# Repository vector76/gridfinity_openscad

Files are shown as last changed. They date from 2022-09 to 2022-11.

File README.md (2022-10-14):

# Gridfinity OpenSCAD Model
This is a recreation of Zack Freedman's gridfinity system in OpenSCAD, 
intended for both experienced OpenSCAD users to customize with added features, 
and also less-experienced OpenSCAD users to customize via options offered in the customizer.

The fit-related dimensions are intended to match Zack's original design exactly.

Options for bins:
* Screw holes are optional, or alternative lengths can be specified
* Magnet pockets are optional, or alternative diameters can be specified
* User-selectable wall thickness and floor thickness
* Generate a filled-in block as a starting point for generating other models (similar in spirit to [this](https://www.printables.com/model/210548-filled-in-gridfinity-boxes-for-customization))
* Any number of subdivisions along X axis (only X subdivisions are implemented)
* Irregular subdivisions along X axis (only X subdivisions are implemented)
* Finger-slide for removing small parts, available as an option
* Label feature available as an option
* Label feature can cover entire X length or only part
* Label feature can be left-justified, right-justified, or centered
* Magnet/screw hole can have printable overhangs as an option (if screw holes and magnet pockets are both used) (similar in spirit to [this](https://www.printables.com/model/269834-gridfinity-template-modified-for-mid-air-holes))
* Option for material-efficient floor that is not flat but saves material/time (similar in spirit to [this](https://www.printables.com/model/265271-gridfinity-lite-economical-plain-storage-bins))
* Fractional-width bins (0.5 units) supported (similar in spirit to [this](https://www.printables.com/model/241907-gridfinity-half-boxes-up-to-3-grids-long-and-6u-hi))

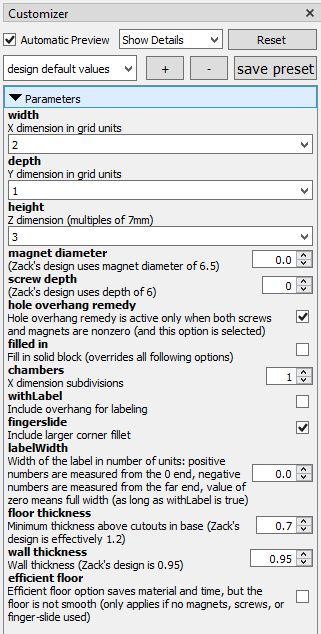
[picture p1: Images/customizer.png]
[]()

Some other models are also included and are also parametric.  Not all of these will be interesting to most people.  Some of them are cosntructions for my own personal use.
* Gridfinity base options
  * Base (just frame)
  * Weighted base includes space for weights and/or screws or magnets
  * Lid/base combination can stack on top of bins and provides base for stacking on top (e.g. for stacking a 1x1 on top of a 3x3)
* Glue stick holder
* Socket holder
* Gridfinity base for Flsun Q5
* Silverware drawer

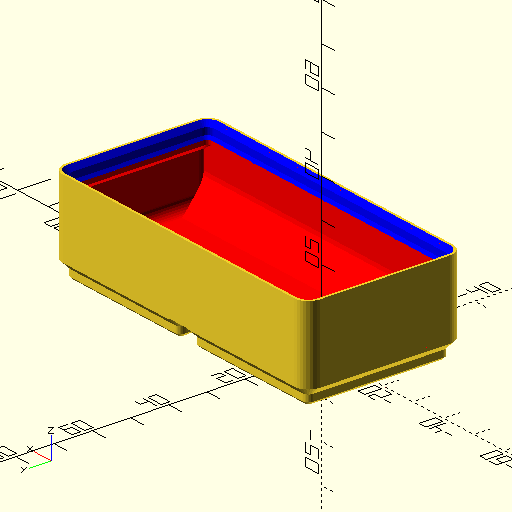
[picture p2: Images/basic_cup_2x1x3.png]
[]()
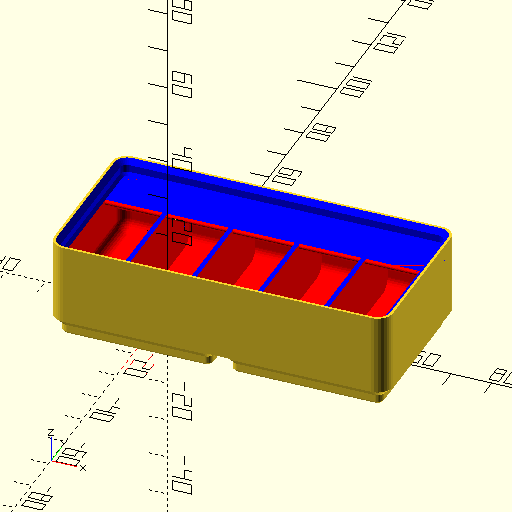
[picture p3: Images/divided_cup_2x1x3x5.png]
[]()
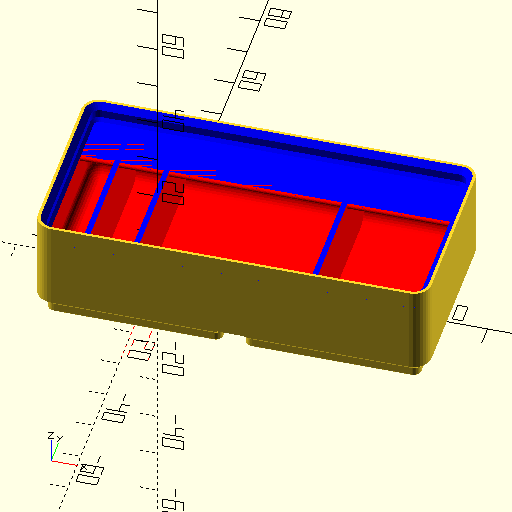
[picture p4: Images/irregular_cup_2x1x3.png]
[]()
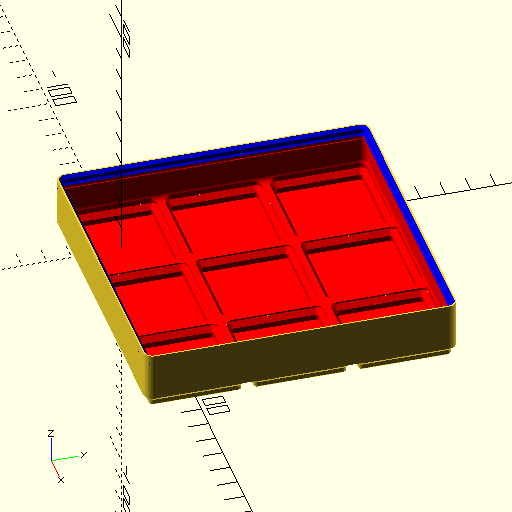
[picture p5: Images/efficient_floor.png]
[]()
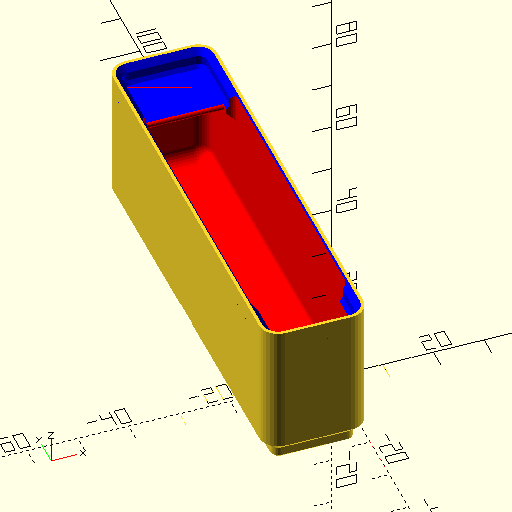
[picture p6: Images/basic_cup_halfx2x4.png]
[]()
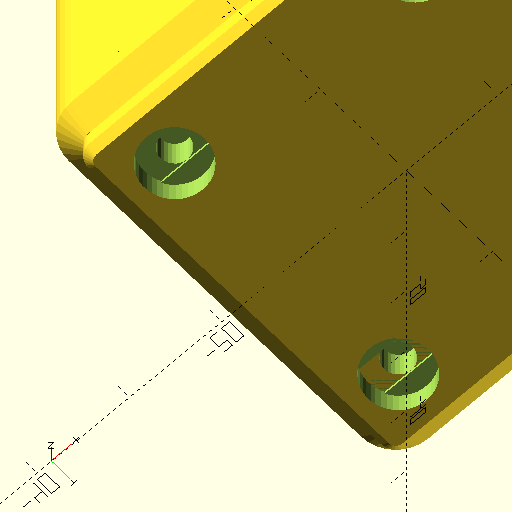
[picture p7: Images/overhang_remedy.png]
[]()
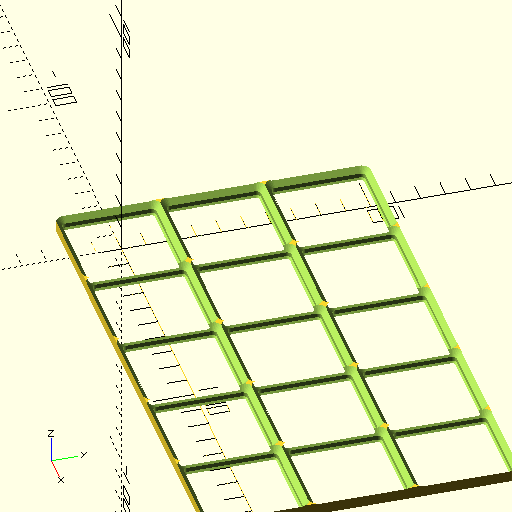
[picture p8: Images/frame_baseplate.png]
[]()
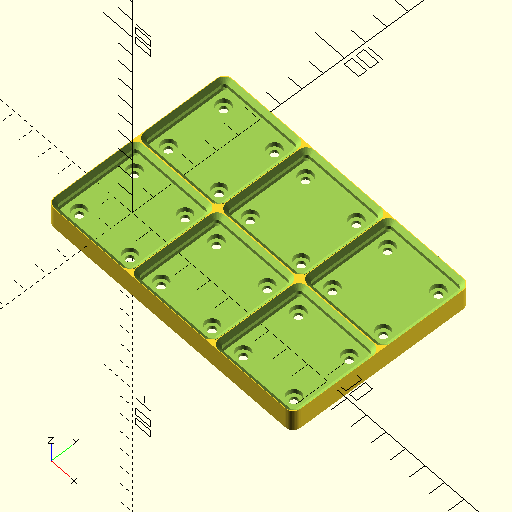
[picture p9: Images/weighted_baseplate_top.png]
[]()
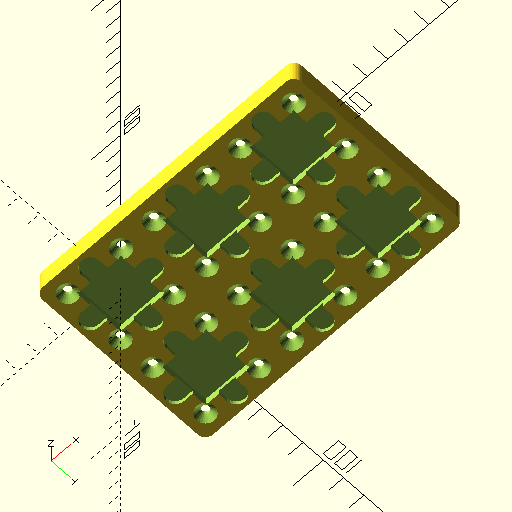
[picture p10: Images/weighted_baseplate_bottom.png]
[]()
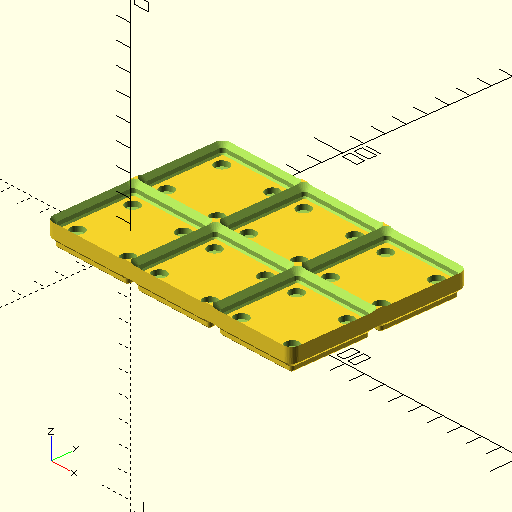
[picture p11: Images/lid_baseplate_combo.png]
[]()

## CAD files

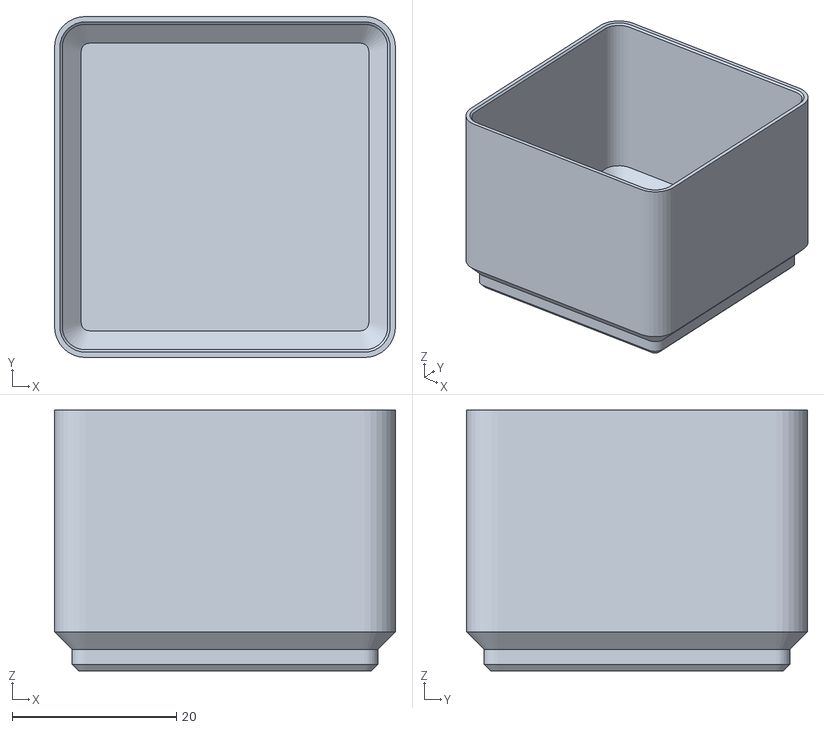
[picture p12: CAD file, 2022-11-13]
Renders/basic_cup_1x1x3_nolip.stl
41.5 x 41.5 x 31.8

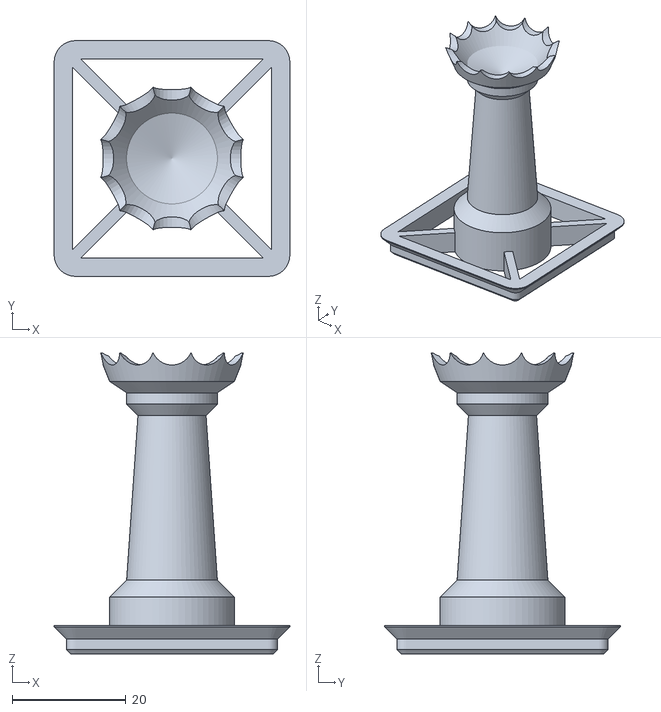
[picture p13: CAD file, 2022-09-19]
Renders/chess/queen.stl
41.5 x 41.5 x 53.0

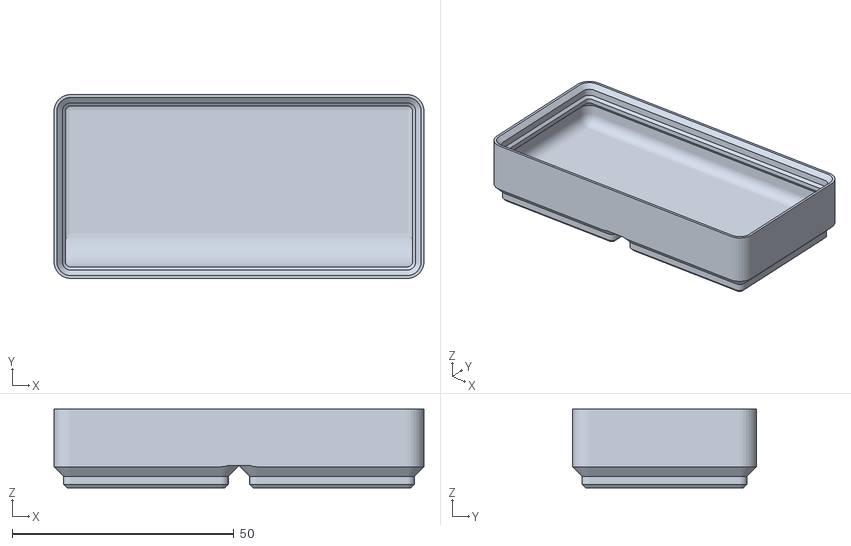
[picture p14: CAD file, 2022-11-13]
Renders/basic_cup_2x1x2.stl
83.5 x 41.5 x 17.8

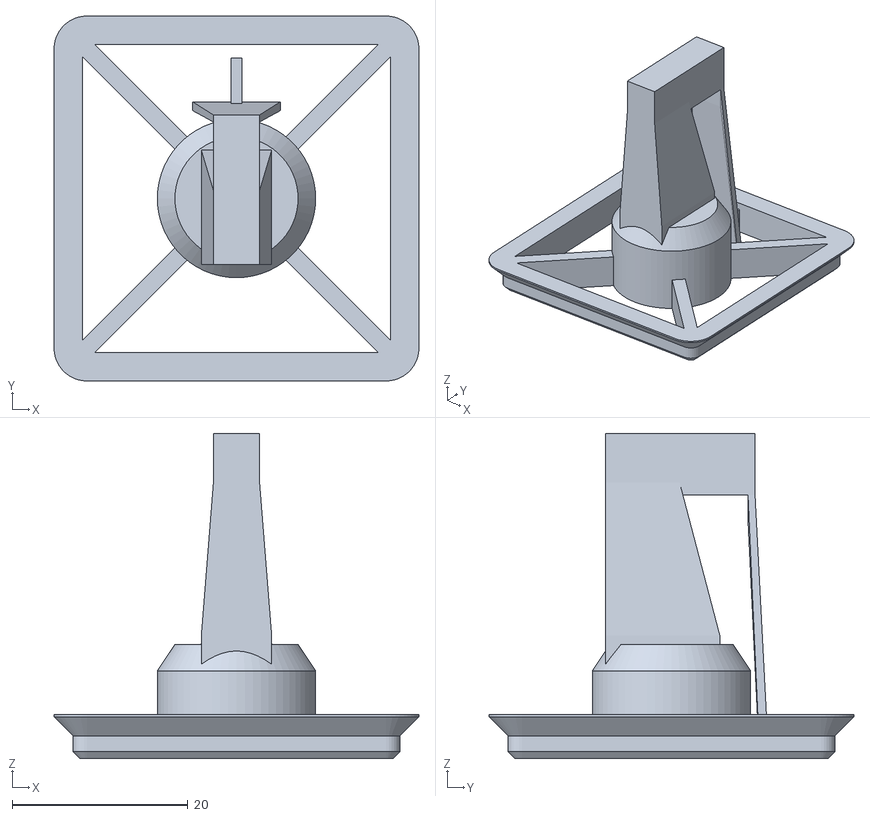
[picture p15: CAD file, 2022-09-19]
Renders/chess/knight.stl
41.5 x 41.5 x 37.0

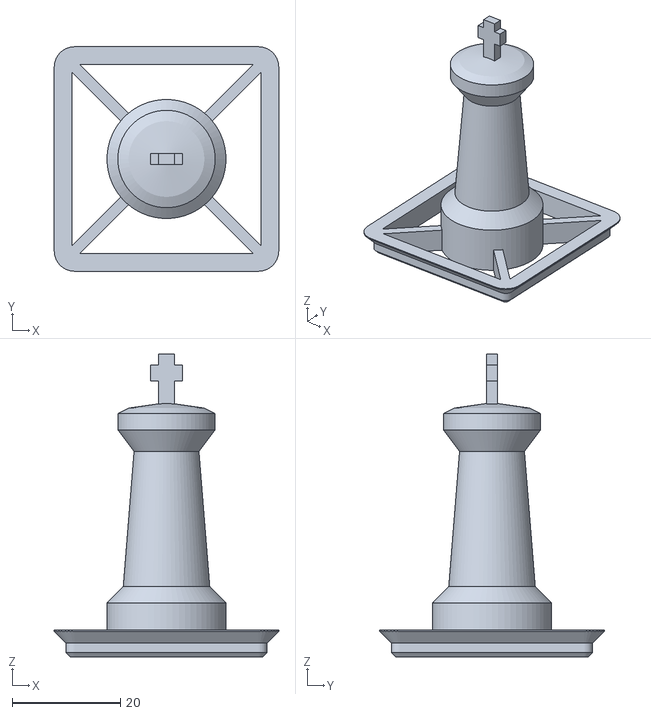
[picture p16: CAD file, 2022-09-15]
Renders/chess/king.stl
41.5 x 41.5 x 56.0

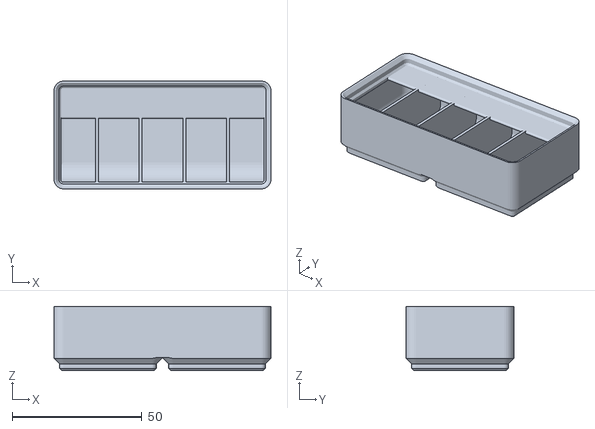
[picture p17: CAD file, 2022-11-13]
Renders/divided_cup_2x1x3x5.stl
83.5 x 41.5 x 24.8

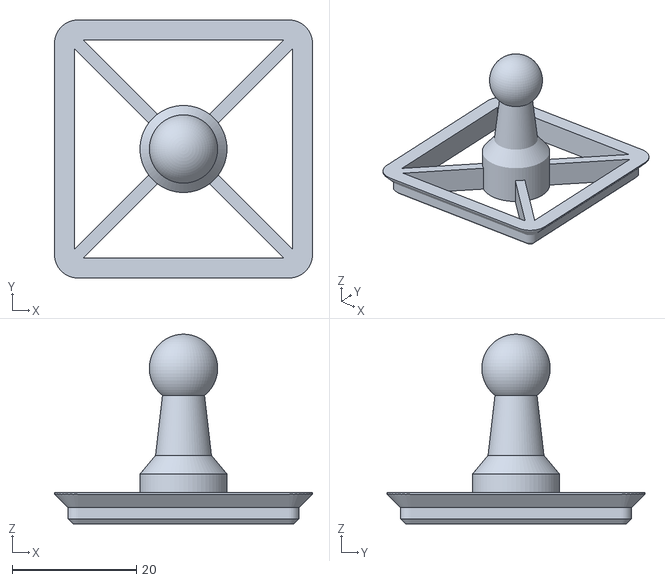
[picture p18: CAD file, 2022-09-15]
Renders/chess/pawn.stl
41.5 x 41.5 x 30.5

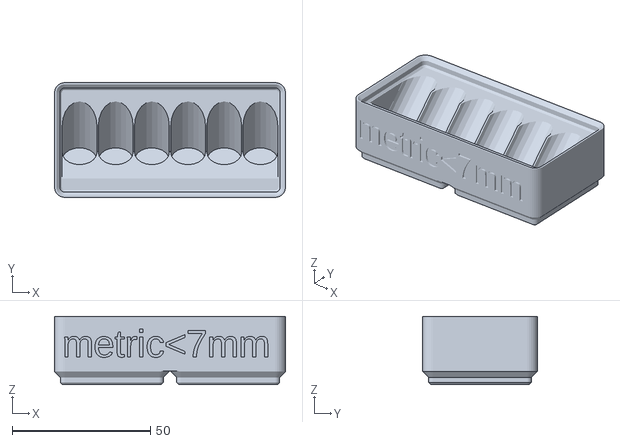
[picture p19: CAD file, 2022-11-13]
Renders/socket_holder_metric_small.stl
83.5 x 41.5 x 24.8

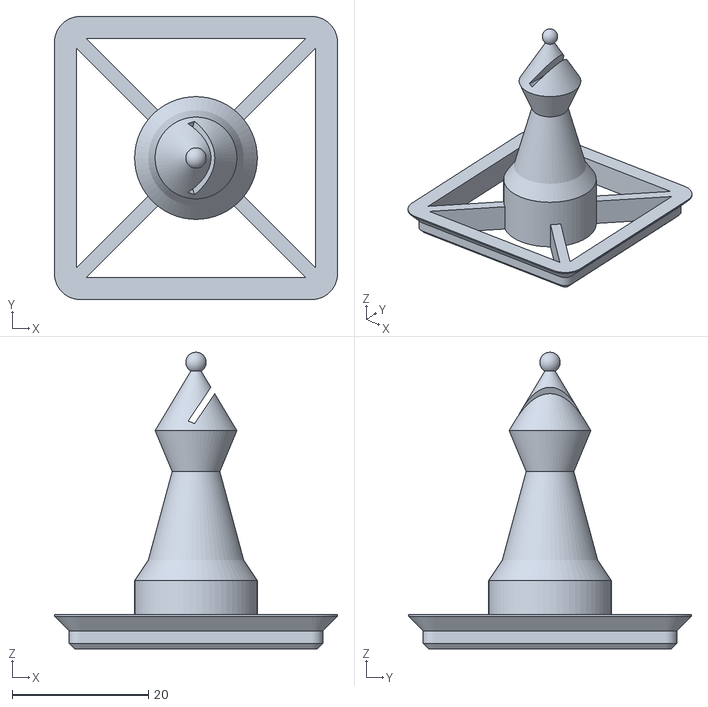
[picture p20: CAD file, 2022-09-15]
Renders/chess/bishop.stl
41.5 x 41.5 x 43.5

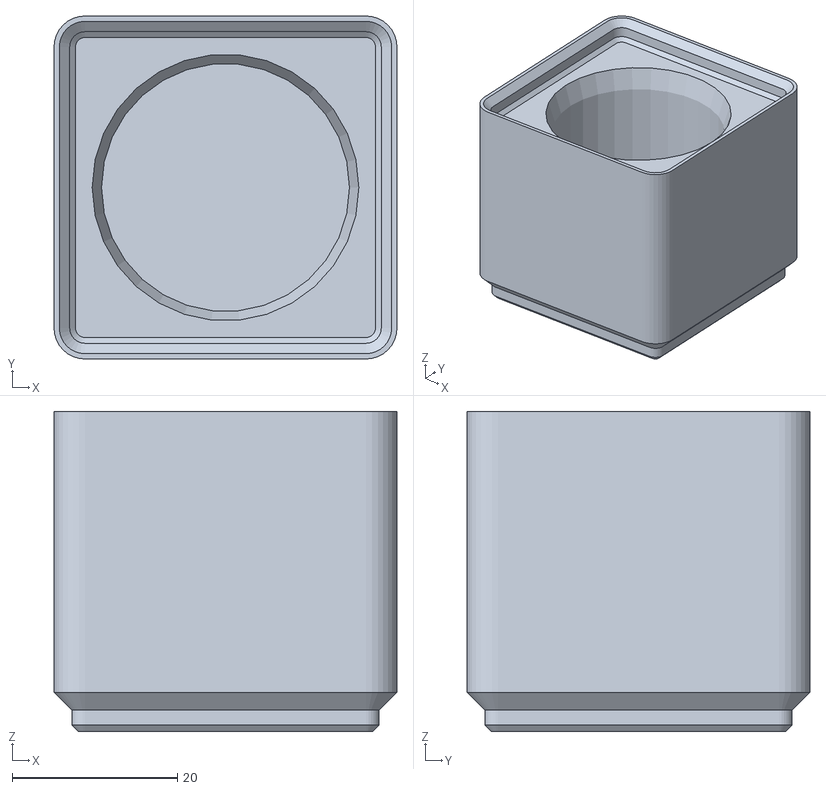
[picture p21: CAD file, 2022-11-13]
Renders/glue_stick_cup.stl
41.5 x 41.5 x 38.8

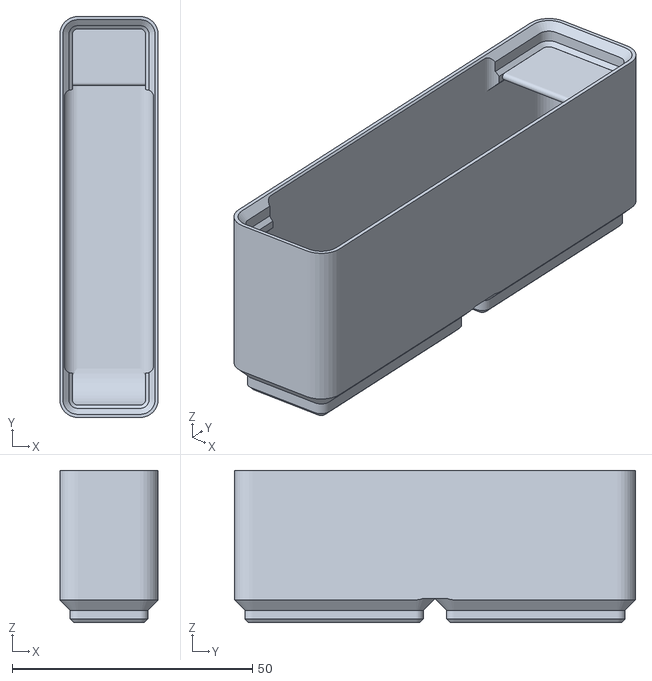
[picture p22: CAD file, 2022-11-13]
Renders/basic_cup_halfx2x4.stl
20.5 x 83.5 x 31.8

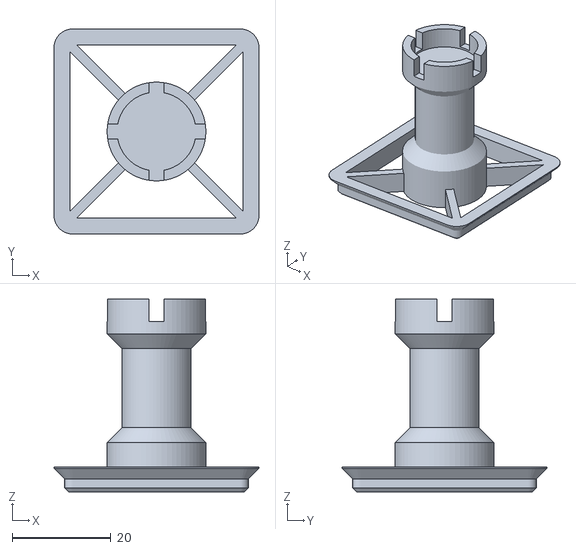
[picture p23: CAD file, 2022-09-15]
Renders/chess/rook.stl
41.5 x 41.5 x 39.0

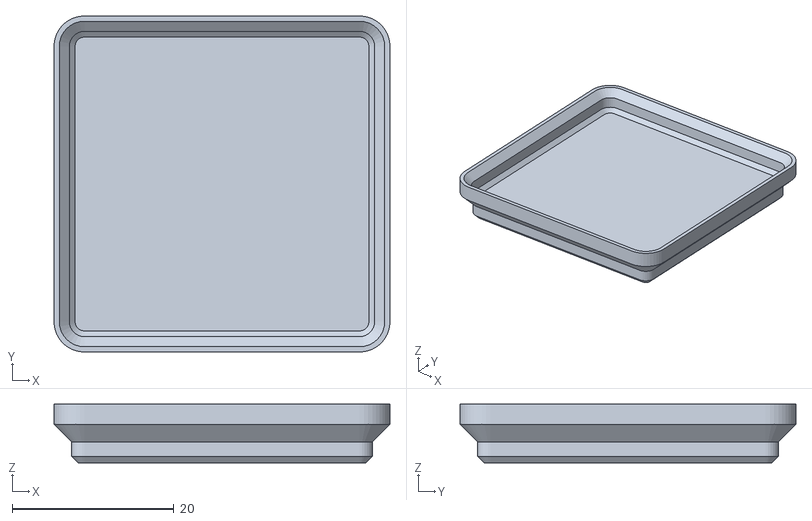
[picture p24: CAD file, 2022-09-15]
Renders/chess/tile.stl
41.5 x 41.5 x 7.25

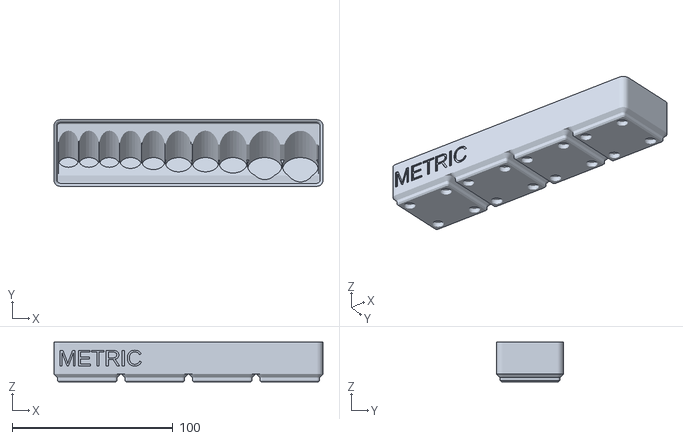
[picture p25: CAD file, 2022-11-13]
Renders/socket_holder_metric.stl
167.5 x 41.5 x 24.8

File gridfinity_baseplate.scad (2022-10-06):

// include instead of use, so we get the pitch
include <gridfinity_modules.scad>

xsize = 5;
ysize = 3;
weighted = false;
lid = false;

if (lid) {
  base_lid(xsize, ysize);
}
else if (weighted) {
  weighted_baseplate(xsize, ysize);
}
else {
  frame_plain(xsize, ysize);
}


module base_lid(num_x, num_y) {
  magnet_od = 6.5;
  magnet_position = min(gridfinity_pitch/2-8, gridfinity_pitch/2-4-magnet_od/2);
  magnet_thickness = 2.4;
  eps = 0.1;
  
  translate([0, 0, 7]) frame_plain(xsize, ysize, trim=0.25);
  difference() {
    grid_block(xsize, ysize, 1, magnet_diameter=0, screw_depth=0);
    gridcopy(num_x, num_y) {
      cornercopy(magnet_position) {
        translate([0, 0, 7-magnet_thickness])
        cylinder(d=magnet_od, h=magnet_thickness+eps, $fn=48);
      }
    }
  }
}


module weighted_baseplate(num_x, num_y) {
  magnet_od = 6.5;
  magnet_position = min(gridfinity_pitch/2-8, gridfinity_pitch/2-4-magnet_od/2);
  magnet_thickness = 2.4;
  eps = 0.1;
  
  difference() {
    frame_plain(num_x, num_y, 6.4);
    
    gridcopy(num_x, num_y) {
      cornercopy(magnet_position) {
        translate([0, 0, -magnet_thickness])
        cylinder(d=magnet_od, h=magnet_thickness+eps, $fn=48);
        
        translate([0, 0, -6.4]) cylinder(d=3.5, h=6.4, $fn=24);
        
        // counter-sunk holes in the bottom
        translate([0, 0, -6.41]) cylinder(d1=8.5, d2=3.5, h=2.5, $fn=24);
      }
      
      translate([-10.7, -10.7, -6.41]) cube([21.4, 21.4, 4.01]);
      
      for (a2=[0,90]) rotate([0, 0, a2])
      hull() for (a=[0, 180]) rotate([0, 0, a])
      translate([-14.9519, 0, -6.41]) cylinder(d=8.5, h=2.01, $fn=24);
    }
  }
}


module frame_plain(num_x, num_y, extra_down=0, trim=0) {
  ht = extra_down > 0 ? 4.4 : 5;
  corner_radius = 3.75;
  corner_position = gridfinity_pitch/2-corner_radius-trim;
  difference() {
    hull() cornercopy(corner_position, num_x, num_y) 
    translate([0, 0, -extra_down]) cylinder(r=corner_radius, h=ht+extra_down, $fn=44);
    translate([0, 0, trim ? 0 : -0.01]) 
    render() gridcopy(num_x, num_y) pad_oversize(margins=1);
  }
}

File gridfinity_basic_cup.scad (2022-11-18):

// include <gridfinity_modules.scad>
use <gridfinity_cup_modules.scad>

// X dimension in grid units
width = 2; // [ 0.5, 1, 2, 3, 4, 5, 6, 7, 8, 9, 10, 11, 12, 13 ]
// Y dimension in grid units
depth = 1; // [ 1, 2, 3, 4, 5, 6, 7, 8, 9, 10, 11, 12, 13 ]
// Z dimension (multiples of 7mm)
height = 3;
// (Zack's design uses magnet diameter of 6.5)
magnet_diameter = 0;  // .1
// (Zack's design uses depth of 6)
screw_depth = 0;
// Hole overhang remedy is active only when both screws and magnets are nonzero (and this option is selected)
hole_overhang_remedy = true;
//Only add attachments (magnets and screw) to box corners (prints faster).
box_corner_attachments_only = false;
// Fill in solid block (overrides all following options)
filled_in = false;
// X dimension subdivisions
chambers = 1;
// Include overhang for labeling (and specify left/right/center justification)
withLabel = "disabled"; // ["disabled", "left", "right", "center", "leftchamber", "rightchamber", "centerchamber"]
// Include larger corner fillet
fingerslide = true;
// Width of the label in number of units, or zero means full width
labelWidth = 0;  // .01
// Minimum thickness above cutouts in base (Zack's design is effectively 1.2)
floor_thickness = 0.7;
// Wall thickness (Zack's design is 0.95)
wall_thickness = 0.95;  // .01
// Efficient floor option saves material and time, but the floor is not smooth (only applies if no magnets, screws, or finger-slide used)
efficient_floor = false;
// When enabled, irregular subdivisions have to be defined in code
irregular_subdivisions = false;
// Enable to subdivide bottom pads to allow half-cell offsets
half_pitch = false;
// Remove some or all of lip
lip_style = "normal";  // [ "normal", "reduced", "none" ]

module end_of_customizer_opts() {}

// Separator positions are defined in terms of grid units from the left end
separator_positions = [ 0.25, 0.5, 1.4 ];

if (filled_in) {
  grid_block(width, depth, height, magnet_diameter=magnet_diameter, 
    screw_depth=screw_depth, hole_overhang_remedy=hole_overhang_remedy,
    half_pitch=half_pitch, box_corner_attachments_only=box_corner_attachments_only);
}
else if (irregular_subdivisions) {
  irregular_cup(
    num_x=width,
    num_y=depth,
    num_z=height,
    withLabel=withLabel,
    labelWidth=labelWidth,
    fingerslide=fingerslide,
    magnet_diameter=magnet_diameter,
    screw_depth=screw_depth,
    floor_thickness=floor_thickness,
    wall_thickness=wall_thickness,
    hole_overhang_remedy=hole_overhang_remedy,
    separator_positions=separator_positions,
    half_pitch=half_pitch,
    lip_style=lip_style,
    box_corner_attachments_only=box_corner_attachments_only
  );
}
else {
  basic_cup(
    num_x=width,
    num_y=depth,
    num_z=height,
    chambers=chambers,
    withLabel=withLabel,
    labelWidth=labelWidth,
    fingerslide=fingerslide,
    magnet_diameter=magnet_diameter,
    screw_depth=screw_depth,
    floor_thickness=floor_thickness,
    wall_thickness=wall_thickness,
    hole_overhang_remedy=hole_overhang_remedy,
    efficient_floor=efficient_floor,
    half_pitch=half_pitch,
    lip_style=lip_style,
    box_corner_attachments_only=box_corner_attachments_only
  );
}

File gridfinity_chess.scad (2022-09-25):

include <gridfinity_modules.scad>

// Select model
part = "tile";  // [ board, tile, pawn, knight, bishop, rook, queen, king ]

if (part == "tile") {
  tile();
}
else if (part == "pawn") {
  pawn();
}
else if (part == "knight") {
  knight();
}
else if (part == "bishop") {
  bishop();
}
else if (part == "rook") {
  rook();
}
else if (part == "queen") {
  queen();
}
else if (part == "king") {
  king();
}
else if (part == "board") {
  board();
  color("#DDDDDD") piece_set();
  color("#505050") piece_set(false);
}


module piece_set(white=true) {
  pawnrow = white ? 1 : 6;
  restrow = white ? 0 : 7;
  
  for (i=[0:7]) {
    translate([i*42, 42*pawnrow, 0]) pawn();
  }
  for (i=[0,1]) {
    translate([0 + 7*i*42, restrow*42, 0]) rook();
    translate([(1 + 5*i)*42, restrow*42, 0]) 
      rotate([0, 0, white ? 0 : 180]) knight();
    translate([(2 + 3*i)*42, restrow*42, 0]) bishop();
  }
  translate([3*42, restrow*42, 0]) queen();
  translate([4*42, restrow*42, 0]) king();
}


module king() {
  base();
  
  rotate_extrude($fn=60)
  polygon([[0, 47], [0, 0], [11, 0], [11, 10], [8, 13], [6, 38],
    [9, 42], [9, 45], [7, 46]]);
  
  translate([-1.5, -1, 47-1]) cube([3, 2, 10]);
  translate([-3, -1, 51]) cube([6, 2, 3]);
}


module queen() {
  base();
  
  difference() {  
    rotate_extrude($fn=60)
    polygon([[0, 45], [0, 0], [11, 0], [11, 10], [8, 13], [6, 42], 
      [8, 44], [8, 46], [11, 48], [13, 53], [12, 53], [8, 48]]);
    
    *%for (a=[0, 60, 120]) rotate([0, 0, a])
    translate([-15, -1.5, 48.5]) cube([30, 3, 10]);
    
    for (a=[0, 30, 60, 90, 120, 150]) rotate([0, 0, a])
    translate([0, 0, 48.5+6])
    rotate([0, 90, 0]) cylinder(d=7.25, h=30, $fn=30, center=true);
  }
}


module knight() {
  base();

  rotate_extrude($fn=60)
  polygon([[0, 13], [0, 0], [9, 0], [9, 10], [7, 13]]);
  
  hull() {
    translate([-4, -7.5, 0]) cube([8, 13, 14]);
    translate([-2.5, -7.5, 30]) cube([5, 8, 3]);
  }
  translate([-2.5-.125, -7.5, 30]) cube([5+.25, 17, 7]);
  
  // support for bridging knight nose (remove afterward)
  hull() {
    translate([-2.625, 9.5-0.8, 27]) cube([5.25, 0.8, 3]);  
    translate([-5, 10, 0]) cube([10, 1, 1]);
  }
  translate([-0.6, 10, 0]) cube([1.2, 6, 5]);
}


module bishop() {
  base();
  
  tz(42) sphere(d=3, $fn=60);
  
  difference() {
    rotate_extrude($fn=60)
    polygon([[0, 42], [0, 0], [9, 0], [9, 10], [7, 13], [3.5, 26], [6, 32]]);
    
    translate([4.5, 0, 40])
    rotate([0, -56, 0])
    cylinder(d=20, h=1, $fn=60);
  }
}


module rook() {
  base();
  
  difference() {
    rotate_extrude($fn=60)
    polygon([[0, 34], [0, 0], [10, 0], [10, 10], [7, 13], [7, 29], 
      [10, 32], [10, 39], [8, 39], [8, 34]]);
    
    for (a=[0, 90]) rotate([0, 0, a]) 
      translate([-15, -1.5, 34.5]) cube([30, 3, 10]);
  }
}


module pawn() {
  base();
  
  tz(25) sphere(d=11, $fn=60);
  
  rotate_extrude($fn=60)
  polygon([[0, 25], [0, 0], [7, 0], [7, 8], [4.5, 11], [3, 24]]);
}


module base() {
  difference() {
    grid_block(1, 1, 0.72, magnet_diameter=0, screw_depth=0);
    difference() {
      cube([35, 35, 30], center=true);
      for (a=[45, 135]) rotate([0, 0, a]) cube([60, 2, 30], center=true);
    }
    
    translate([-21, -21, 5]) cube([42, 42, 42]);
  }
}


module board() {  // 64 tiles in alternating colors
  tz(-3.55) for (ti=[0:7]) for (tj=[0:7]) translate([42*ti, 42*tj, 0]) 
    color((ti+tj)%2 == 0 ? "darkblue" : "lightblue")
    render() tile();
}


module tile() {
  grid_block(1, 1, 0.5, magnet_diameter=0, screw_depth=0);
}


module tz(z) {
  translate([0, 0, z]) children();
}

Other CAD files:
Renders/divided_cup_2x1x2x5.stl
Renders/socket_holder_imperial.stl
Renders/socket_holder_metric_stacking.stl
Renders/filled_block_2x1x3x5.stl
gridfinity_cup_modules.scad
Renders/base_lid.stl
Renders/baseplate.stl
Renders/flsun_q5.stl
Renders/socket_holder_imperial_big.stl
Renders/socket_holder_imperial_small.stl
Renders/weighted_baseplate.stl
gridfinity_flsun_q5.scad
gridfinity_glue_stick.scad
gridfinity_modules.scad
gridfinity_silverware.scad
gridfinity_socket_holder.scad
modules/gridfinity_cup_modules.scad
modules/gridfinity_modules.scad

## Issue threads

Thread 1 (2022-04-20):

Basic cup should be centered

RussNelson, 2022-04-20:
If you create a basic cup with any values other than 1,1 only the first grid unit is centered. The whole module should be centered.

RussNelson, 2022-04-20:
I suggest this because the largest glue stick you can hold without overlapping the edges is 34mm. Bigger than that, and it needs to use a 2x2 storage unit to hold the stick.

vector76, 2022-04-21:
I've updated grid block to have an option to center the assembly in X/Y (but not Z), somewhat analogous to the option in the native OpenSCAD cube().  7a81cb26ac3db598b1b274acb1f8680bb33545fa

Closed 2022-04-21.

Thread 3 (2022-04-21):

why import?

RussNelson, 2022-04-21:
Why are Zack's baseplates being imported into gridfinity_baseplate.scad? Is that just for comparison's sake?
Also, the simple baseplate's holes are not fully cut out. I had to make this change. Is this correct?
-    render() gridcopy(num_x, num_y) pad_oversize(margins=1);
+    translate([0,0,-0.01]) render() gridcopy(num_x, num_y) pad_oversize(margins=1);

vector76, 2022-04-21:
oops!  I meant to remove those imports.  I use those during construction to confirm the dimensions match exactly.

The plain frame has a negative space that coincides with the bottom of the positive space, which doesn't render properly in preview mode (appears not fully cut out) but when rendered it is fully cut out.  Shifting downward by 0.01 will fix the preview at the expense of a very small deviation from Zack's models.  Overall, I think it is close enough and the preview appearance does matter, so I'm willing to include your update for that.

vector76, 2022-04-21:
addressed by 1be92633c44ab8c1248270a54d34d8ec4def1df2

Closed 2022-04-21.

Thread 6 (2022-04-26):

Need to increase bottom thickness; which approach to differences between this and the original?

universalist, 2022-04-26:
Hi there, and thanks a lot for this project!
I've tried it out (with satisfaction and success), but I noticed that there are some differences to the original parts.
Especially the bottom is much thinner, which is a problem because with large layer heights the bottom layer of the compartment becomes just one single layer, resulting in a bad print.
I'd like to propose a fix and create a pull request for that (it would be my very first pull request, but I have experience in OpenSCAD).
I assume that the current bottom thickness was (like the bottom hole height) reduced to maximize the compartment space, so I'd honor that, and would add two options:

1. to set a user-defined minimum thickness above the holes and the bottom cutouts
2. to not maxmize compartment size, but replicate the dimensions of Zacks design

What do you think, does this make sense, would you accept this as a solution? Please let me know what you think.

Regards, Chris

vector76, 2022-04-27:
Yes, I think this makes sense.  Since I was not intending to use the M3 screw holes or magnet holes, I thought it was a waste of space and also a waste of filament to keep the floor height.

By removing (or shortening) the m3 screw holes, the floor can be lower, which I adopted as the default, although I see your point about having an option to more closely mimic Zack's design or choose an alternative floor thickness.

Here is a separate idea that might relate: currently there is an option for holes or no holes, where holes implies the counter-bore holes that fit either M3 screws or magnets.  Since the OpenSCAD design is intended to be more customized and has less need to be universal, I had contemplated making screws or magnets (or both or neither) independent options.

I mention the holes because it creates a constraint where a low floor will have the holes poke through, and without the holes the floor can be lower, and is instead constrained by the grooves between the pads.

What I think would make sense is an option for:
* Magnets: diameter or zero for no magnet holes
* M3 holes: depth or zero for no M3 holes
* Minimum floor thickness

If M3 holes are desired, the minimum floor thickness will create a higher floor, or if M3 holes are not desired or if they are shorter, then the floor will be lower.  The default values for these three options can replicate Zack's design, and the options can be tweaked while maintaining constraints so that the holes won't poke through the floor.

I will give this a think and probably implement it this way.

RussNelson, 2022-04-27:
That is a good idea. You could put the holes / no_holes variable into the top of the file and let the customizer do its thing.

vector76, 2022-08-13:
I believe this last commit implements these features.  The defaults are zero (no hole for screw or magnet) but the values for Zack's design are documented in the customizer (6.0 for screw length and 6.5 for magnet diameter) and the floor thickness causes the floor to be the specified distance above whichever is the tallest.

Open to feedback if I have broken something, but I think this is now complete.

Closed 2022-08-13.

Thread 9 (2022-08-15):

Setting Height above 7 x 7MM

crazyn0va, 2022-08-15:
I was trying to modify the code to allow for a multiple like 11, it shows up fine in the graphic but when I go to export the file I get a different, smaller height. Here is what I have modified:

`// Z dimension (multiples of 7mm)
height = 11;// [2, 3, 4, 5, 6, 7, 8, 9, 10, 11]`

Thanks for helping a SCAD noob.

crazyn0va, 2022-08-15:
Looks like user error, Thanks for the great work!

Closed 2022-08-15.

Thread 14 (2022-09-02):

Not an issue but a question

hvddrift, 2022-09-02:
Re your socket modules. Mine only has one parameter. Should there be more? If not how does it work?

For example if I have a socket set that is

26mm, 25mm, 23mm, 22mm, 17mm etc in diameter can I create a print to suit?

vector76, 2022-09-02:
I had use a single parameter ("part") to generate a small number of variants from a single file, and to generate a custom one you would need to edit the code.

I think you could create what you want by defining part to be 100 or something and then add something like this:
`socket_holder(3, [26,25,23,17], "Custom");`

The first number (3 in this case) is the number of gridfinity units, and the list [26,25,23,17] specifies the number of sockets and their sizes.  The string "Custom" is added as a label and can be whatever you want.

So that should be how you customize it, however, it does look like there is a collision for sockets larger than 24mm and it won't fit properly.  (You can see the red cylinders poking through the model.)

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

If you lower the height by using `num_z` of about 2.3, it looks like it will clear:

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

Hope that helps!

Closed 2022-09-11.

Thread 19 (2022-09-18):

Idea: Half-size bins

rcarmo, 2022-09-18:
I just saw this:

https://www.reddit.com/r/gridfinity/comments/xgn50x/i_have_expanded_my_half_bins_to_9_sizes/

...and it makes a weird kind of sense for some small, long parts (including electronics components, like headers).

Not a priority, but might be an interesting feature to add.

vector76, 2022-09-18:
Huh, interesting.  So if I understand correctly, these
- Still fits on the normal 42 x 42 base cell size
- Only supports half cell width, not say 1.5 or 2.5 cell width
- Length is a whole multiple of cell size
- Stackable on itself
- Magnets and screws in the base probably don't make sense
- Looks like part of the lip is removed for better access

This is interesting.  I like this idea.  I will think about it.

ostat, 2022-09-18:
I'm not sure I would see value in a half sized bin.
Printing two half sized bins would use more plastic than one normal bin with a divider.

That being said being able to set a size in half steps might be handy. Someone might need a size of 3.5x7.5 to fit a specific item, or fill out a draw.

Stacking would be an issue.

vector76, 2022-09-19:
Ok I've made it flexible so it can accept fractional sizes for x (not for y, seems less important).
Added a drop-down to the customizer interface so 0.5 is easily accessible to customizer users without having to guess.
Other fractional values are allowed too, like 0.7 or 0.33 or 1.5.
This is added in commit 7eb04f7131b548b6ddc819d7f7ccfb5450ba0b41 so I'm closing this issue, but I'm still open to feedback, especially if I broke something.

Closed 2022-09-19.

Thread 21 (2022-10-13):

Feature Request: centered labeling shelves

mrmattmorris, 2022-10-13:
The labeling shelves serve two purposes: 1) holding labels;  and 2) acting as a finger catch to lift bins up when they're surrounded by adjacent bins.  As currently implemented, label shelves are always 'left- or right-justified'.  This makes it a bit awkward to lift wide bins that use short label shelves  -- where the lift is happening away from the center of mass.

It could be useful to offer a option to center the label shelves for users who would prefer 'center justification'.

I've already implemented these changes to gridfinity_cup_modules.scad.  I can make a pull request if the owner is interested.

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

mrmattmorris, 2022-10-13:
Whoops, this is already underway as [PR#20](https://github.com/vector76/gridfinity_openscad/pull/20).  Consider this a vote in support.

vector76, 2022-10-13:
Thank you. This has been implemented by #20 but I haven't had a chance to review and merge it. I am guessing will probably be accepting that PR but if you have some commentary, since you have been considering the same issue, I would be interested to hear it.

vector76, 2022-10-13:
Thanks, I will close this issue as essentially duplicate.

Closed 2022-10-13.

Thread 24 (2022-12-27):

Unable to use z-height lower than 2

MrUzagi, 2022-12-27:
This is using the files downloaded from GitHub Dec 13th where the latest modifications dates are Dec 1st (on my computer at GMT +1.)

Setting the height of less than two (actually less than 1.26 after some investigation) the base of the cup is missing the middle bits.

A 1x1 cup with z at 2:
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

A 1x1 cup with z at 1:
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

Editing the height in the script we can check smaller steps.
1.20
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

1.25
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

At 1.26 it looks closed
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

MrUzagi, 2022-12-27:
I've only recently started to familiarize myself with OpenSCAD so I haven't been able to track down the reason for this as of yet.

vector76, 2022-12-27:
Indeed, some of the cutaways for cutting downward from the lip and upward from the bottom were interfering with each other.

I just pushed an update and these are now reduced, and also now it automatically forces 'reduced' or 'none' lip style for very low Z.

Some of the internal fillets are not great, and the finger slide is still broken for low Z, but it should fix the issues you were having.

MrUzagi, 2022-12-31:
Looking good now. Thanks, and happy new year. 🎆

Closed 2022-12-31.

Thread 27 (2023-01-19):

"filled in" should optionally not ignore "lip style"

avxmw, 2023-01-19:
Trying to make a box with a flat top to then cut the shapes for my screwdrivers I noticed I can not fill the box completely, but the lip always remains. I'm trying to make a uniform height without boundaries and for this the lip is in the way.

As such I'd like to request an option to actually fill in everything as cutting of the lip obviously reduces total height.

ostat, 2024-08-06:
I added this suggestion to Gridfinity Extended (which is built on this library). When using filled in, you can chose the lip style.
https://github.com/ostat/gridfinity_extended_openscad

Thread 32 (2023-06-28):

Request - baseplates with half-pitch lid.

Rivenwolf2, 2023-06-28:
Currently, baseplates are only available in standard pitch. This also applies when "lid" option is checked. When bins are set half-pitch, stacking a larger lid to cover adjacent standard-pitch bins causes interference issues.

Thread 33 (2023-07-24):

How to edit total height of a box?

iweputo, 2023-07-24:
Im using customized bin heights and not following the 7mm rule from Zack, is there any way of adjusting overall height like kennetek OpenSCAD desing so i can edit height in 1mm increments and not in 7mm blocks?

thanks for all the work the files are almost perfect, just need this slight adjustment so it can be perfectly parametric

benzvan, 2024-03-15:
In case you haven't discovered the answer yet, you can modify the `gridfinity_modules.scad` file line 2 for gridfinity_zpitch to change the height of your own generated objects.

benzvan, 2024-03-15:
You should also be able to use a fractional different `num_z` value for equal to your desired height divided by 7.

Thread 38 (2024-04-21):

Labels on two sides instead of one

pupeno, 2024-04-21:
I love this bins. I think I have already printed around 8kg worth of filament into these bins. I'll post some pics when I'm done. I wrote some scripts to generate all the bins I require and slice them automatically. It's amazing.

One problem I'm having is that when organizing my drawers some drawers are organized in rows, some in columns, and I want all the labels readable when you open the drawer, so sometimes I may find myself throwing away a 2 by 3 bin to print a 3 by 2. I'd love to have an option to add labels to two sides, so the bins are more flexible and the result is less wasteful.

ostat, 2024-08-05:
I added this suggestion to Gridfinity Extended (which is built on this library).
https://github.com/ostat/gridfinity_extended_openscad

pupeno, 2024-08-05:
Cool. Thank you very much.

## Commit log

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2022-04-20 magic numbers now have names and some adjustments flow properly
    [basic_cup_2x1x3.stl, gridfinity_basic_cup.scad, gridfinity_modules.scad]
2022-04-20 added basic frame and weighted baseplate
    [frame_plain.stl, gridfinity_baseplate.scad, gridfinity_modules.scad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]
2022-04-20 add a glue stick holder cuz Zack's is too small
    [gridfinity_glue_stick.scad]
2022-04-21 remove imports (included by accident) tiny shift to clean up preview of plain frame
    [gridfinity_baseplate.scad]
2022-04-21 grid_block has option to center glue stick cup generalized to handle larger round things
    [glue_stick_cup.stl, gridfinity_glue_stick.scad, gridfinity_modules.scad]
2022-04-21 Add a simple grid to the top of an FLSUN q5
    [gridfinity_flsun_q5.scad]
2022-04-21 use existing definition of frame_plain
    Introduces dependency but avoids management of multiple redundant copies
    [gridfinity_flsun_q5.scad]
2022-04-21 adding stl for flsun_q5 model from RussNelson
    [flsun_q5.stl]
2022-04-22 added batch file to regenerate stl files canonicalize stl files so files are identical if and only if the meshes are equivalent (openscad is not repeatable by itself)
    [basic_cup_2x1x3.stl, flsun_q5.stl, frame_plain.stl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]
2022-04-22 added divided version of cups fixed a couple minor bugs
    [basic_cup_2x1x3.stl, divided_cup_2x1x3x5.stl, gridfinity_basic_cup.scad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]
2022-04-22 fix file name mistake (height is 2, not 3)
    [basic_cup_2x1x2.stl, divided_cup_2x1x2x5.stl]
2022-04-22 fixed some serious bugs added labels when divider bins are 3 or more units tall
    [divided_cup_2x1x2x5.stl, divided_cup_2x1x3x5.stl, gridfinity_basic_cup.scad]
2022-04-25 socket holder: Add socket holder
    [gridfinity_socket_holder.scad]
2022-04-26 socket holder: Better margin, wiggle room to easily remove sockets
    [gridfinity_socket_holder.scad]
2022-04-26 socket holders: Replace "stackable" variable with plain z height variable
    [gridfinity_socket_holder.scad]
2022-04-27 Adjust whitespace so consistent with other files
    [gridfinity_socket_holder.scad]
2022-04-27 oops, i broke it. fixed.
    [gridfinity_socket_holder.scad]
2022-04-27 Rendered STLs from earboxer
    [socket_holder_imperial.stl, socket_holder_imperial_big.stl, socket_holder_imperial_small.stl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]
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2022-05-30 Creating folder structure for easy maintance
    [basic_cup_2x1x2.stl, divided_cup_2x1x2x5.stl, divided_cup_2x1x3x5.stl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]
2022-05-30 some clean up and coloring for better understanding of model parts
    [gridfinity_basic_cup.scad, gridfinity_modules.scad]
2022-05-31 gridfinity_baseplate redundant with frame_plain frame_plain is probably a bad name, changed to simply baseplate (gridfinity is implicit) updated batch file to specify cup dimensions instead of part n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
    [baseplate.stl, gridfinity_baseplate.stl, socket_holder_metric.stl]
2022-06-22 Fix small holes/gaps when printing at 0.3 layer height
    We need 0.2mm extra so that the slicer doesn't consider this just a single pass
    [gridfinity_basic_cup.scad]
2022-08-13 Updated rendered models to reflect slightly thicker floor
    [basic_cup_2x1x2.stl, divided_cup_2x1x2x5.stl, divided_cup_2x1x3x5.stl]
2022-08-13 Allows choice of screw length, magnet diameter, and floor thickness as discussed in #6 Also updated so customizer is a bit more intuitive and documented values to match Zack's design Caught and fixed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
    [basic_cup_2x1x2.stl, divided_cup_2x1x2x5.stl, divided_cup_2x1x3x5.stl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]
2022-08-20 Cup promoted to parametric module (inputs, not global variables) Defaults represent Zack's design (magnets, screws, floor thickness) Basic cup model just uses module and contains my preferences (over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
    [gridfinity_basic_cup.scad, gridfinity_cup_modules.scad]
2022-08-20 magnet diameter first, then screw depth, consistently (in case it is ever specified without keywords)
    [gridfinity_glue_stick.scad, gridfinity_modules.scad]
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2022-08-24 fingerSlide option was missing (customizer had no effect)
    [gridfinity_basic_cup.scad]
2022-08-25 make explicit the recommendation of using keyword parameters and follow this policy also fix the batch file
    [gridfinity_cup_modules.scad]
2022-09-07 added option for a baseplate/lid combination
    [base_lid.stl, gridfinity_baseplate.scad]
2022-09-09 Allow support for magnets wider than 8mm
    [gridfinity_modules.scad]
2022-09-10 Fix wall thinness
    When slicing the resulting STL files for a 0.4 nozzle, the back wall (below the label) was always too thin (with one line thickness less than the others) and cracked easily.
    This makes the cut very slightly smaller and (at least for me) ensures that boxes print correctly.
    [gridfinity_cup_modules.scad]
2022-09-10 Changing comment format so it shows up within OpenSCAD customizer Also annotating with '.1' so customizer allows fractional label sizes
    [gridfinity_basic_cup.scad]
2022-09-11 instead of a thicker (fixed) wall, make it variable to suit a variety of possible cases also make the default match Zack's original of 0.95 mm wall thickness
    [gridfinity_basic_cup.scad, gridfinity_cup_modules.scad]
2022-09-11 adding my silverware organizer because why not
    [gridfinity_silverware.scad]
2022-09-14 added option for overhang fix (easier to print when both magnet and screw holes are present) added option for 'efficient floor' which saves material at the expense of having a smooth floor
    [gridfinity_basic_cup.scad, gridfinity_cup_modules.scad, gridfinity_modules.scad]
2022-09-15 chess board and pieces
    [bishop.stl, gridfinity_chess.scad, king.stl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]
2022-09-19 adjusted queen to look less like rook, and added support (using bridging) for knight
    [gridfinity_chess.scad, knight.stl, queen.stl]
2022-09-19 flatten folder structure to prevent user error when files downloaded individually regenerate stl files, no significant difference
    [base_lid.stl, baseplate.stl, divided_cup_2x1x2x5.stl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]
2022-09-19 added simple option for generating filled-in blocks and added sample STL
    [filled_block_2x1x3x5.stl, gridfinity_basic_cup.scad]
2022-09-19 added half-width option (drop-down in customizer for intuitive interface) other fractional widths work too, accessible through code
    [basic_cup_halfx2x4.stl, gridfinity_basic_cup.scad, gridfinity_cup_modules.scad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]
2022-09-20 added option for irregular subdivision of cups
    [divided_cup_2x1x2x5.stl, divided_cup_2x1x3x5.stl, gridfinity_basic_cup.scad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]
2022-09-25 update chess model to handle flattening of module folder
    [gridfinity_chess.scad]
2022-10-01 update allows half-cell subdivisions of the bottom pads also allows odd-size in the Y direction (with or without half-cell subdivisions)
    [gridfinity_basic_cup.scad, gridfinity_cup_modules.scad, gridfinity_modules.scad]
2022-10-05 Allow setting of label position to center, round label.
    [gridfinity_cup_modules.scad]
2022-10-06 generalize so gridfinity_pitch can change and everything "should" still work...
    [gridfinity_baseplate.scad, gridfinity_cup_modules.scad, gridfinity_modules.scad]
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2022-10-14 Update documentation Retain default behavior of no label Negative label widths treated as zero (insignificant, maybe slightly less counter-intuitive)
    [gridfinity_basic_cup.scad, gridfinity_cup_modules.scad]
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2022-11-13 add option to remove inner lip also re-render all the meshes
    [base_lid.stl, basic_cup_2x1x2.stl, basic_cup_halfx2x4.stl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]
2022-11-13 forgot to add example of cup with no inner lip
    [basic_cup_1x1x3_nolip.stl]
2022-11-13 lip style (now three styles) instead of remove lip also cleaned up efficient floor to fix ugly transition at bottom
    [basic_cup_1x1x3_nolip.stl, gridfinity_basic_cup.scad, gridfinity_cup_modules.scad]
2022-11-18 Added option to put attachments only in box corners
    [gridfinity_basic_cup.scad, gridfinity_cup_modules.scad, gridfinity_modules.scad]
2022-11-30 added option to produce sharp corners instead of standard rounded corners (must modify the file to use this option)
    [gridfinity_modules.scad]
2022-11-30 accidentally committed version with sharp corners. default needs to be rounded corners.
    [gridfinity_modules.scad]
2022-12-27 includes some fixes for very low Z height
    [gridfinity_cup_modules.scad]
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
